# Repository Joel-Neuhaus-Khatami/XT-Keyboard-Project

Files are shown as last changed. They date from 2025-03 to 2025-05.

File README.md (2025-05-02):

XT Keyboard Project:

This repo is for all the files used in designing and manufacturing a mechanical keyboard that I made from scratch
The keyboard itself is a modified XT layout, which was a very popular layout for 1980's keyboards.

The case is inspired by the IBM Model F77, Cherry G80-0418 and the modern NCR80.
Later angularity and side-bezel thickness was inspired by the Pravetz 16 from the Soviet Union and various NCR G80 varieties, for example the NCR G80-0478.

The pcb is designed with Kailh Hotswap Sockets (Although I just soldered my switches directly), all of which are south facing to avoid Cherry profile interference. 
In addition, the pcb supports many different layout varieties, such as stepped caps lock, split left- and right shift, and split backspace compatibility.
These layouts have also been designed to have the correct clearance for the Hotswap footprint.
The PCB was originally designed with using the ATMega32u4, but after a failed iteration, it was replaced with an RP2040 PCB design instead.
Using the RP2040 enabled QMK firmware compatibility + VIA.
Due to the case dimensions, the pcb does not have an onboard USB type C recepticle, rather using a 4-pin Molex Pico EZmate connector and a daughterboard,
in this instance the UDB (Unified Daughterboard) C4.
The new RP2040 based pcb introduces new quality of life features, such as readily available GND, 3V, RESET, SWD and SWC pins for ISP programming, making troubleshooting a lot simpler
should there be need to program the chip's bootloader.

1. Layout

Capture2

The layout is a mix of the standard HHKB for the Alphanumerical section, XT-esque left side F-row and a 3x5 1U grid inspired by the IBM Model F-77

2. Schematics

Early visualization of switch matrix (This layout was changed tremendously due to later solutions for multiple layouts)
switch_matrix

Switch matrix translated to Kicad schematics
pcb_v3

3. Case

Top case w/ plate


Top and Bottom case side profile



Back view including slit for UDB implementation


Inside view of Top case, showing plate top mount + UDB implementation


Inside view of Bottom case


Bottom


To be posted:
Produced aluminium case

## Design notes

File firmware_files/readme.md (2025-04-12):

# jxt

jxt

*A short description of the keyboard/project*

* Keyboard Maintainer: [Joel Ramin Neuhaus-Khatami](https://github.com/Joel Ramin Neuhaus-Khatami)
* Hardware Supported: *The PCBs, controllers supported*
* Hardware Availability: *Links to where you can find this hardware*

Make example for this keyboard (after setting up your build environment):

    make jxt:default

Flashing example for this keyboard:

    make jxt:default:flash

See the [build environment setup](https://docs.qmk.fm/#/getting_started_build_tools) and the [make instructions](https://docs.qmk.fm/#/getting_started_make_guide) for more information. Brand new to QMK? Start with our [Complete Newbs Guide](https://docs.qmk.fm/#/newbs).

## Bootloader

Enter the bootloader in 3 ways:

* **Bootmagic reset**: Hold down the key at (0,0) in the matrix (usually the top left key or Escape) and plug in the keyboard
* **Physical reset button**: Briefly press the button on the back of the PCB - some may have pads you must short instead
* **Keycode in layout**: Press the key mapped to `QK_BOOT` if it is available

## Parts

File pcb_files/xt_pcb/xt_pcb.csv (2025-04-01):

Source: | C:\Users\Gremlosh\Documents\Programming\Other_projects\XT Keyboard\PCB\xt_pcb\xt_pcb.kicad_sch
Date: | 2025-04-01T20:27:29+0200
Tool: | Eeschema 8.0.8
Generator: | C:\Program Files\KiCad\8.0\bin\scripting\plugins/bom_csv_grouped_by_value.py
Component Count: | 201
Collated Components:
Item | Qty | Reference(s) | Value | LibPart | Footprint | Datasheet | DNP | Datasheet | Description | Footprint | Sim.Device | Sim.Pins
1 | 1 | BT1 | SW_Push | Switch:SW_Push | Button_Switch_SMD:SW_SPST_TL3342 | ~ |  | ~ | Push button switch, generic, two pins | Button_Switch_SMD:SW_SPST_TL3342
2 | 3 | C1, C2, C3 | 100n | Device:C | Capacitor_SMD:C_0402_1005Metric | ~ |  | ~ | Unpolarized capacitor | Capacitor_SMD:C_0402_1005Metric
3 | 2 | C4, C5 | 10u | Device:C | Capacitor_SMD:C_0603_1608Metric | ~ |  | ~ | Unpolarized capacitor | Capacitor_SMD:C_0603_1608Metric
4 | 2 | C6, C7 | 12p | Device:C | Capacitor_SMD:C_0402_1005Metric | ~ |  | ~ | Unpolarized capacitor | Capacitor_SMD:C_0402_1005Metric
5 | 1 | C8 | 1u | Device:C | Capacitor_SMD:C_0402_1005Metric | ~ |  | ~ | Unpolarized capacitor | Capacitor_SMD:C_0402_1005Metric
6 | 86 | D1, D2, D3, D4, D5, D6, D7, D8, D9, D10, D11, D12, D13, D14, D15, D16, D18, D19, D20, D21, D22, D23, D24, D25, D26, D27, D28, D29, D30, D31, D32, D33, D34, D35, D36, D37, D38, D39, D40, D41, D42, D43, D44, D45, D46, D47, D48, D49, D50, D51, D52, D53, D54, D55, D56, D57, D58, D59, D60, D61, D62, D63, D64, D65, D66, D67, D68, D69, D70, D71, D72, D73, D74, D75, D76, D77, D78, D79, D80, D81, D82, D83, D84, D85, D86, D87 | D | Device:D | Diode_SMD:D_SOD-123 | ~ |  | ~ | Diode | Diode_SMD:D_SOD-123 | D | 1=K 2=A
7 | 1 | J1 | Conn_01x04_Socket | Connector:Conn_01x04_Socket | Connector_JST:JST_SH_SM04B-SRSS-TB_1x04-1MP_P1.00mm_Horizontal | ~ |  | ~ | Generic connector, single row, 01x04, script generated | Connector_JST:JST_SH_SM04B-SRSS-TB_1x04-1MP_P1.00mm_Horizontal
8 | 1 | J2 | USB_C_Receptacle_USB2.0_16P | Connector:USB_C_Receptacle_USB2.0_16P | Connector_USB:USB_C_Receptacle_HRO_TYPE-C-31-M-12 | https://www.usb.org/sites/default/files/documents/usb_type-c.zip |  | https://www.usb.org/sites/default/files/documents/usb_type-c.zip | USB 2.0-only 16P Type-C Receptacle connector | Connector_USB:USB_C_Receptacle_HRO_TYPE-C-31-M-12
9 | 1 | R1 | 10k | Device:R | Resistor_SMD:R_0402_1005Metric | ~ |  | ~ | Resistor | Resistor_SMD:R_0402_1005Metric
10 | 2 | R2, R3 | 22 | Device:R | Resistor_SMD:R_0402_1005Metric | ~ |  | ~ | Resistor | Resistor_SMD:R_0402_1005Metric
11 | 2 | R4, R5 | 5k1 | Device:R | Resistor_SMD:R_0402_1005Metric | ~ |  | ~ | Resistor | Resistor_SMD:R_0402_1005Metric
12 | 1 | SW1 | SW_Push | Switch:SW_Push | PCM_Switch_Keyboard_Hotswap_Kailh:SW_Hotswap_Kailh_MX_Plated_2.00u | ~ |  | ~ | Push button switch, generic, two pins | PCM_Switch_Keyboard_Hotswap_Kailh:SW_Hotswap_Kailh_MX_Plated_2.00u
13 | 77 | SW2, SW3, SW4, SW5, SW6, SW7, SW8, SW9, SW10, SW11, SW12, SW13, SW14, SW15, SW16, SW17, SW19, SW20, SW21, SW22, SW23, SW25, SW26, SW27, SW28, SW29, SW30, SW31, SW32, SW33, SW34, SW35, SW36, SW38, SW39, SW40, SW42, SW43, SW45, SW46, SW47, SW48, SW49, SW50, SW51, SW52, SW53, SW54, SW55, SW57, SW58, SW59, SW60, SW62, SW64, SW66, SW67, SW68, SW69, SW70, SW71, SW72, SW73, SW74, SW75, SW76, SW77, SW78, SW79, SW80, SW81, SW82, SW83, SW87, SW88, SW89, SW90 | SW_Push | Switch:SW_Push | PCM_Switch_Keyboard_Hotswap_Kailh:SW_Hotswap_Kailh_MX_Plated_1.00u | ~ |  | ~ | Push button switch, generic, two pins | PCM_Switch_Keyboard_Hotswap_Kailh:SW_Hotswap_Kailh_MX_Plated_1.00u
14 | 2 | SW24, SW37 | SW_Push | Switch:SW_Push | PCM_Switch_Keyboard_Hotswap_Kailh:SW_Hotswap_Kailh_MX_Plated_1.50u | ~ |  | ~ | Push button switch, generic, two pins | PCM_Switch_Keyboard_Hotswap_Kailh:SW_Hotswap_Kailh_MX_Plated_1.50u
15 | 2 | SW41, SW97 | SW_Push | Switch:SW_Push | PCM_Switch_Keyboard_Hotswap_Kailh:SW_Hotswap_Kailh_MX_Plated_1.75u | ~ |  | ~ | Push button switch, generic, two pins | PCM_Switch_Keyboard_Hotswap_Kailh:SW_Hotswap_Kailh_MX_Plated_1.75u
16 | 4 | SW44, SW63, SW84, SW86 | SW_Push | Switch:SW_Push | PCM_Switch_Keyboard_Hotswap_Kailh:SW_Hotswap_Kailh_MX_Plated_1.25u | ~ |  | ~ | Push button switch, generic, two pins | PCM_Switch_Keyboard_Hotswap_Kailh:SW_Hotswap_Kailh_MX_Plated_1.25u
17 | 2 | SW56, SW61 | SW_Push | Switch:SW_Push | PCM_Switch_Keyboard_Hotswap_Kailh:SW_Hotswap_Kailh_MX_Plated_2.25u | ~ |  | ~ | Push button switch, generic, two pins | PCM_Switch_Keyboard_Hotswap_Kailh:SW_Hotswap_Kailh_MX_Plated_2.25u
18 | 1 | SW85 | SW_Push | Switch:SW_Push | PCM_Switch_Keyboard_Hotswap_Kailh:SW_Hotswap_Kailh_MX_Plated_6.25u | ~ |  | ~ | Push button switch, generic, two pins | PCM_Switch_Keyboard_Hotswap_Kailh:SW_Hotswap_Kailh_MX_Plated_6.25u
19 | 1 | SW91 | SW_Push | Switch:SW_Push | PCM_Mounting_Keyboard_Stabilizer:Stabilizer_Cherry_MX_6.25u | ~ |  | ~ | Push button switch, generic, two pins | PCM_Mounting_Keyboard_Stabilizer:Stabilizer_Cherry_MX_6.25u
20 | 4 | SW92, SW93, SW94, SW95 | SW_Push | Switch:SW_Push | PCM_Mounting_Keyboard_Stabilizer:Stabilizer_Cherry_MX_2.00u | ~ |  | ~ | Push button switch, generic, two pins | PCM_Mounting_Keyboard_Stabilizer:Stabilizer_Cherry_MX_2.00u
21 | 1 | SW96 | SW_Push | Switch:SW_Push | PCM_Switch_Keyboard_Hotswap_Kailh:SW_Hotswap_Kailh_MX_Plated_2.75u | ~ |  | ~ | Push button switch, generic, two pins | PCM_Switch_Keyboard_Hotswap_Kailh:SW_Hotswap_Kailh_MX_Plated_2.75u
22 | 1 | U1 | AMS1117-3.3 | Regulator_Linear:AMS1117-3.3 | Package_TO_SOT_SMD:SOT-223-3_TabPin2 | http://www.advanced-monolithic.com/pdf/ds1117.pdf |  | http://www.advanced-monolithic.com/pdf/ds1117.pdf | 1A Low Dropout regulator, positive, 3.3V fixed output, SOT-223 | Package_TO_SOT_SMD:SOT-223-3_TabPin2
23 | 1 | U2 | ATmega32U4-A | MCU_Microchip_ATmega:ATmega32U4-A | Package_QFP:TQFP-44_10x10mm_P0.8mm | http://ww1.microchip.com/downloads/en/DeviceDoc/Atmel-7766-8-bit-AVR-ATmega16U4-32U4_Datasheet.pdf |  | http://ww1.microchip.com/downloads/en/DeviceDoc/Atmel-7766-8-bit-AVR-ATmega16U4-32U4_Datasheet.pdf | 16MHz, 32kB Flash, 2.5kB SRAM, 1kB EEPROM, USB 2.0, TQFP-44 | Package_QFP:TQFP-44_10x10mm_P0.8mm
24 | 1 | U3 | USB6B1 | Power_Protection:USB6B1 | Package_SO:SOIC-8_3.9x4.9mm_P1.27mm | http://www.st.com/content/ccc/resource/technical/document/datasheet/3e/ec/b2/54/b2/76/47/90/CD00001361.pdf/files/CD00001361.pdf/jcr:content/translations/en.CD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 |  | http://www.st.com/content/ccc/resource/technical/document/datasheet/3e/ec/b2/54/b2/76/47/90/CD00001361.pdf/files/CD00001361.pdf/jcr:content/translations/en.CD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 | 5V Data line protection | Package_SO:SOIC-8_3.9x4.9mm_P1.27mm
25 | 1 | Y1 | Crystal_GND24_Small | Device:Crystal_GND24_Small | Crystal:Crystal_SMD_3225-4Pin_3.2x2.5mm | ~ |  | ~ | Four pin crystal, GND on pins 2 and 4, small symbol | Crystal:Crystal_SMD_3225-4Pin_3.2x2.5mm

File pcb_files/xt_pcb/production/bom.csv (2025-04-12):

Designator | Footprint | Quantity | Value | LCSC Part #
BT1 | SW_SPST_TL3342 | 1 | SW_Push
C1, C2, C3 | 0402 | 3 | 100n
C4, C5 | 0603 | 2 | 10u
C6, C7 | 0402 | 2 | 12p
C8 | 0402 | 1 | 1u
D1, D10, D11, D12, D13, D14, D15, D16, D18, D19, D2, D20, D21, D22, D23, D24, D25, D26, D27, D28, D29, D3, D30, D31, D32, D33, D34, D35, D36, D37, D38, D39, D4, D40, D41, D42, D43, D44, D45, D46, D47, D48, D49, D5, D50, D51, D52, D53, D54, D55, D56, D57, D58, D59, D6, D60, D61, D62, D63, D64, D65, D66, D67, D68, D69, D7, D70, D71, D72, D73, D74, D75, D76, D77, D78, D79, D8, D80, D81, D82, D83, D84, D85, D86, D87, D9 | D_SOD-123 | 86 | D
J1 | MOLEX_781710004 | 1 | Conn_01x04_Socket
R1 | 0402 | 1 | 10k
R2, R3 | 0402 | 2 | 22
SW1 | SW_Hotswap_Kailh_MX_Plated_2.00u | 1 | SW_Push
SW10, SW11, SW12, SW13, SW14, SW15, SW16, SW17, SW19, SW2, SW20, SW21, SW22, SW23, SW25, SW26, SW27, SW28, SW29, SW3, SW30, SW31, SW32, SW33, SW34, SW35, SW36, SW38, SW39, SW4, SW40, SW42, SW43, SW45, SW46, SW47, SW48, SW49, SW5, SW50, SW51, SW52, SW53, SW54, SW55, SW57, SW58, SW59, SW6, SW60, SW62, SW64, SW66, SW67, SW68, SW69, SW7, SW70, SW71, SW72, SW73, SW74, SW75, SW76, SW77, SW78, SW79, SW8, SW80, SW81, SW82, SW83, SW87, SW88, SW89, SW9, SW90 | SW_Hotswap_Kailh_MX_Plated_1.00u | 77 | SW_Push
SW24, SW37 | SW_Hotswap_Kailh_MX_Plated_1.50u | 2 | SW_Push
SW41, SW97 | SW_Hotswap_Kailh_MX_Plated_1.75u | 2 | SW_Push
SW44, SW63, SW84, SW86 | SW_Hotswap_Kailh_MX_Plated_1.25u | 4 | SW_Push
SW56, SW61 | SW_Hotswap_Kailh_MX_Plated_2.25u | 2 | SW_Push
SW85 | SW_Hotswap_Kailh_MX_Plated_6.25u | 1 | SW_Push
SW91 | Stabilizer_Cherry_MX_6.25u | 1 | SW_Push
SW92, SW93, SW94, SW95 | Stabilizer_Cherry_MX_2.00u | 4 | SW_Push
SW96 | SW_Hotswap_Kailh_MX_Plated_2.75u | 1 | SW_Push
U1 | SOT-223-3_TabPin2 | 1 | AMS1117-3.3
U2 | TQFP-44_10x10mm_P0.8mm | 1 | ATmega32U4-A
Y1 | Crystal_SMD_3225-4Pin_3.2x2.5mm | 1 | Crystal_GND24_Small

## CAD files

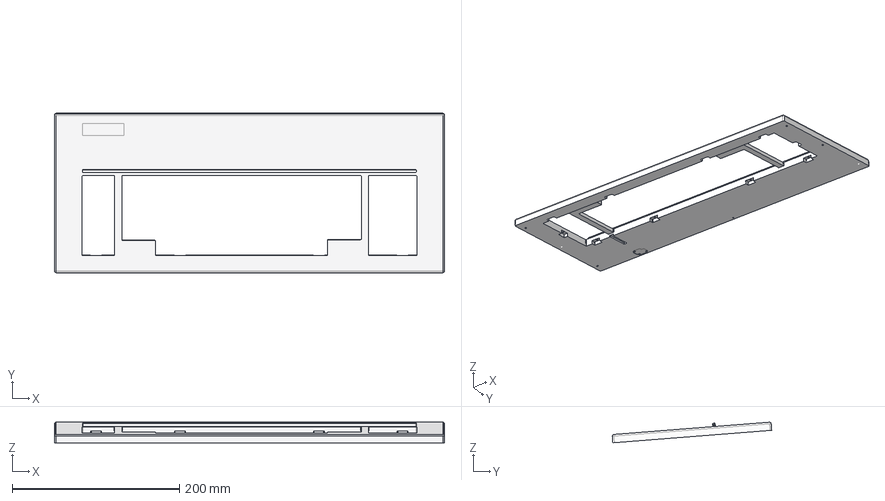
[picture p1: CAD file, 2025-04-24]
case_files/top_case.step
467.1 x 191.0 x 24.7 mm

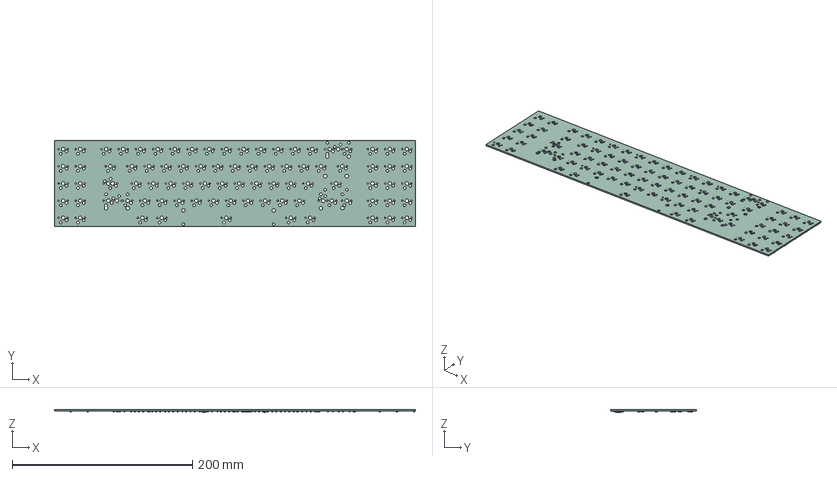
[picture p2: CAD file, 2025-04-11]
pcb_files/xt_pcb/xt_pcb.step
400.1 x 95.2 x 3.35 mm
D_SOD_123 x 86
R_0402_1005Metric x 3
SOT_223
C_0402_1005Metric x 6
TQFP_44_10x10mm_P08mm
Crystal_SMD_3225-4Pin_3.2x2.5mm
C_0603_1608Metric x 2
SW_SPST_TL3342
xt_pcb_PCB

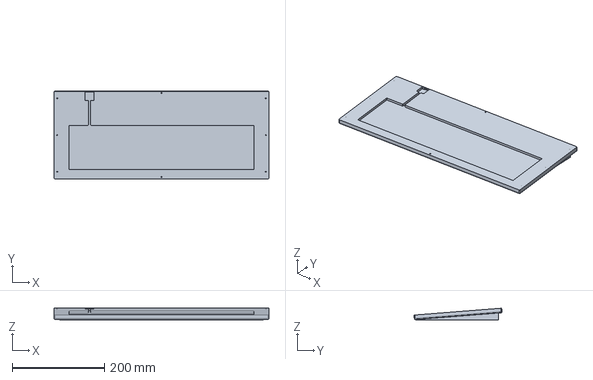
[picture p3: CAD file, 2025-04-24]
case_files/bottom_case.step
467.0 x 191.0 x 25.3 mm

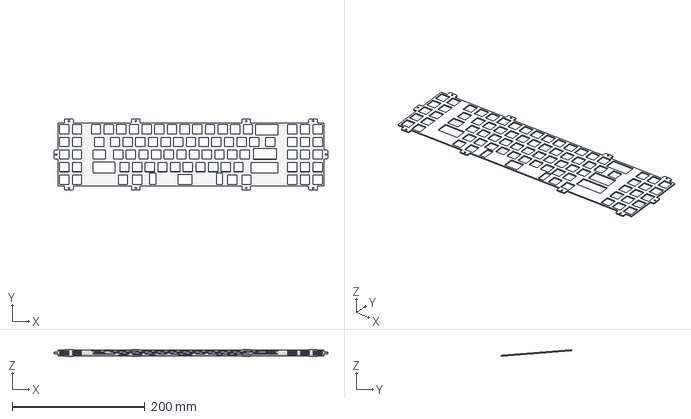
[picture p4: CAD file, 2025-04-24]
case_files/plate.step
412.0 x 107.1 x 9.91 mm

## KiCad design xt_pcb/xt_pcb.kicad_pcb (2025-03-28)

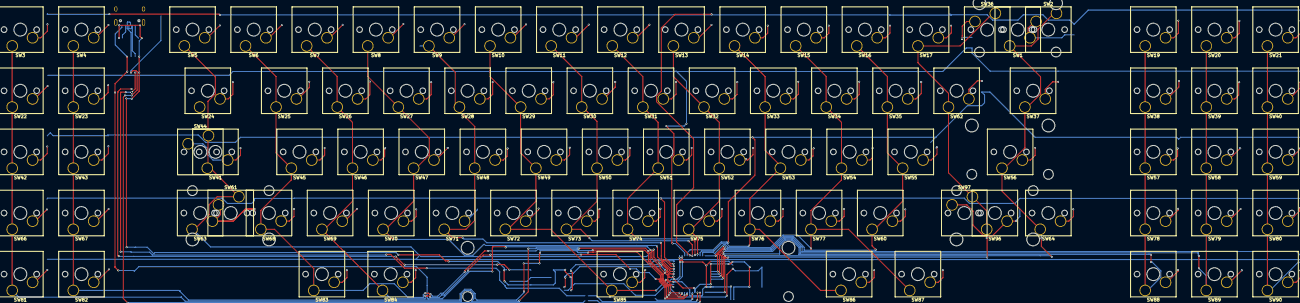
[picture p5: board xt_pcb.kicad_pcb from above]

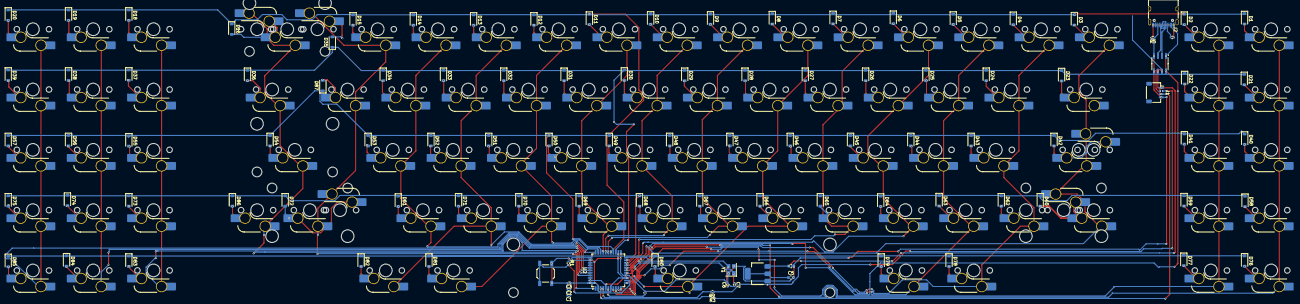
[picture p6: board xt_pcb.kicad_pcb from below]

Board: 2 copper layers, 201 parts (106 on the bottom side), 126 nets.

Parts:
BT1: SW_Push; SW_SPST_TL3342
C1, C2, C3: 100n; C_0402_1005Metric
C4, C5: 10u; C_0603_1608Metric
C6, C7: 12p; C_0402_1005Metric
C8: 1u; C_0402_1005Metric
D1, D2, D3, D4, D5, D6, D7, D8, D9, D10, D11, D12, D13, D14, D15, D16, D18, D19, D20, D21, D22, D23, D24, D25, D26, D27, D28, D29, D30, D31, D32, D33, D34, D35, D36, D37, D38, D39, D40, D41, D42, D43, D44, D45, D46, D47, D48, D49, D50, D51, D52, D53, D54, D55, D56, D57, D58, D59, D60, D61, D62, D63, D64, D65, D66, D67, D68, D69, D70, D71, D72, D73, D74, D75, D76, D77, D78, D79, D80, D81, D82, D83, D84, D85, D86, D87: D; D_SOD-123
J1: Conn_01x04_Socket; JST_SH_SM04B-SRSS-TB_1x04-1MP_P1.00mm_Horizontal
J2: USB_C_Receptacle_USB2.0_16P; USB_C_Receptacle_HRO_TYPE-C-31-M-12
R1: 10k; R_0402_1005Metric
R2, R3: 22; R_0402_1005Metric
R4, R5: 5k1; R_0402_1005Metric
SW1: SW_Push; SW_Hotswap_Kailh_MX_Plated_2.00u
SW2, SW3, SW4, SW5, SW6, SW7, SW8, SW9, SW10, SW11, SW12, SW13, SW14, SW15, SW16, SW17, SW19, SW20, SW21, SW22, SW23, SW25, SW26, SW27, SW28, SW29, SW30, SW31, SW32, SW33, SW34, SW35, SW36, SW38, SW39, SW40, SW42, SW43, SW45, SW46, SW47, SW48, SW49, SW50, SW51, SW52, SW53, SW54, SW55, SW57, SW58, SW59, SW60, SW62, SW64, SW66, SW67, SW68, SW69, SW70, SW71, SW72, SW73, SW74, SW75, SW76, SW77, SW78, SW79, SW80, SW81, SW82, SW83, SW87, SW88, SW89, SW90: SW_Push; SW_Hotswap_Kailh_MX_Plated_1.00u
SW24, SW37: SW_Push; SW_Hotswap_Kailh_MX_Plated_1.50u
SW41, SW97: SW_Push; SW_Hotswap_Kailh_MX_Plated_1.75u
SW44, SW63, SW84, SW86: SW_Push; SW_Hotswap_Kailh_MX_Plated_1.25u
SW56, SW61: SW_Push; SW_Hotswap_Kailh_MX_Plated_2.25u
SW85: SW_Push; SW_Hotswap_Kailh_MX_Plated_6.25u
SW91: SW_Push; Stabilizer_Cherry_MX_6.25u
SW92, SW93, SW94, SW95: SW_Push; Stabilizer_Cherry_MX_2.00u
SW96: SW_Push; SW_Hotswap_Kailh_MX_Plated_2.75u
U1: AMS1117-3.3; SOT-223-3_TabPin2
U2: ATmega32U4-A; TQFP-44_10x10mm_P0.8mm
U3: USB6B1; SOIC-8_3.9x4.9mm_P1.27mm
Y1: Crystal_GND24_Small; Crystal_SMD_3225-4Pin_3.2x2.5mm

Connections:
+3.3V: C5.1, U1.2 (VO)
+5V: C4.1, J1.1, U1.3 (VI)
C1: SW3.2, SW22.2, SW42.2, SW66.2, SW81.2, U2.11 (PB3)
C2: SW4.2, SW23.2, SW43.2, SW67.2, SW82.2, U2.9 (PB1)
C3: SW5.2, SW24.2, SW41.2, SW44.2, SW61.2, SW63.2, U2.18 (PD0)
C4: SW6.2, SW25.2, SW45.2, SW68.2, SW83.2, U2.10 (PB2)
C5: SW7.2, SW26.2, SW46.2, SW69.2, SW84.2, U2.8 (PB0)
C6: SW8.2, SW27.2, SW47.2, SW70.2, U2.19 (PD1)
C7: SW9.2, SW28.2, SW48.2, SW71.2, U2.20 (PD2)
C8: SW10.2, SW29.2, SW49.2, SW72.2, SW85.2, U2.12 (PB7)
C9: SW11.2, SW30.2, SW50.2, SW73.2, U2.28 (PB4)
C10: SW12.2, SW31.2, SW51.2, SW74.2, U2.29 (PB5)
C11: SW13.2, SW32.2, SW52.2, SW75.2, U2.30 (PB6)
C12: SW14.2, SW33.2, SW53.2, SW76.2, SW86.2, U2.31 (PC6)
C13: SW15.2, SW34.2, SW54.2, SW77.2, SW87.2, U2.32 (PC7)
C14: SW16.2, SW35.2, SW55.2, SW60.2, U2.33 (~HWB/PE2)
C15: SW17.2, SW36.2, SW62.2, SW96.2, SW97.2, U2.1 (PE6)
C16: SW1.2, SW2.2, SW37.2, SW56.2, SW64.2, U2.41 (PF0)
C17: SW19.2, SW38.2, SW57.2, SW78.2, SW88.2, U2.40 (PF1)
C18: SW20.2, SW39.2, SW58.2, SW79.2, SW89.2, U2.39 (PF4)
C19: SW21.2, SW40.2, SW59.2, SW80.2, SW90.2, U2.38 (PF5)
D+: J1.2, R2.1, U3.6 (I/O2)
D-: J1.3, R3.1, U3.7 (I/O1)
GND: BT1.1, C1.2, C2.2, C3.2, C4.2, C5.2, C6.2, C7.2, C8.2, J1.4, J2.A1 (GND), J2.A12 (GND), J2.B1 (GND), J2.B12 (GND), R4.2, R5.2, U1.1 (GND), U2.5 (UGND), U2.15 (GND), U2.23 (GND), U2.35 (GND), U2.43 (GND), U3.4 (GND), U3.5 (GND), Y1.2, Y1.4
unnamed: D1.2 (A), SW3.1
unnamed: D2.2 (A), SW4.1
unnamed: D3.2 (A), SW5.1
unnamed: D4.2 (A), SW6.1
unnamed: D5.2 (A), SW7.1
unnamed: D6.2 (A), SW8.1
unnamed: D7.2 (A), SW9.1
unnamed: D8.2 (A), SW10.1
unnamed: D9.2 (A), SW11.1
unnamed: D10.2 (A), SW12.1
unnamed: D11.2 (A), SW13.1
unnamed: D12.2 (A), SW14.1
unnamed: D13.2 (A), SW15.1
unnamed: D14.2 (A), SW16.1
unnamed: D15.2 (A), SW17.1
unnamed: D16.2 (A), SW1.1, SW2.1
unnamed: D18.2 (A), SW19.1
unnamed: D19.2 (A), SW20.1
unnamed: D20.2 (A), SW21.1
unnamed: D21.2 (A), SW22.1
unnamed: D22.2 (A), SW23.1
unnamed: D23.2 (A), SW24.1
unnamed: D24.2 (A), SW25.1
unnamed: D25.2 (A), SW26.1
unnamed: D26.2 (A), SW27.1
unnamed: D27.2 (A), SW28.1
unnamed: D28.2 (A), SW29.1
unnamed: D29.2 (A), SW30.1
unnamed: D30.2 (A), SW31.1
unnamed: D31.2 (A), SW32.1
unnamed: D32.2 (A), SW33.1
unnamed: D33.2 (A), SW34.1
unnamed: D34.2 (A), SW35.1
unnamed: D35.2 (A), SW36.1
unnamed: D36.2 (A), SW37.1
unnamed: D37.2 (A), SW38.1
unnamed: D38.2 (A), SW39.1
unnamed: D39.2 (A), SW40.1
unnamed: D40.2 (A), SW42.1
unnamed: D41.2 (A), SW43.1
unnamed: D42.2 (A), SW41.1, SW44.1
unnamed: D43.2 (A), SW45.1
unnamed: D44.2 (A), SW46.1
unnamed: D45.2 (A), SW47.1
unnamed: D46.2 (A), SW48.1
unnamed: D47.2 (A), SW49.1
unnamed: D48.2 (A), SW50.1
unnamed: D49.2 (A), SW51.1
unnamed: D50.2 (A), SW52.1
unnamed: D51.2 (A), SW53.1
unnamed: D52.2 (A), SW54.1
unnamed: D53.2 (A), SW55.1
unnamed: D54.2 (A), SW56.1
unnamed: D55.2 (A), SW57.1
unnamed: D56.2 (A), SW58.1
unnamed: D57.2 (A), SW59.1
unnamed: D58.2 (A), SW66.1
unnamed: D59.2 (A), SW67.1
unnamed: D60.2 (A), SW61.1, SW63.1
unnamed: D61.2 (A), SW60.1
unnamed: D62.2 (A), SW68.1
unnamed: D63.2 (A), SW69.1
unnamed: D64.2 (A), SW70.1
unnamed: D65.2 (A), SW71.1
unnamed: D66.2 (A), SW72.1
unnamed: D67.2 (A), SW73.1
unnamed: D68.2 (A), SW74.1
unnamed: D69.2 (A), SW75.1
unnamed: D70.2 (A), SW76.1
unnamed: D71.2 (A), SW77.1
unnamed: D72.2 (A), SW96.1, SW97.1
unnamed: D73.2 (A), SW78.1
unnamed: D74.2 (A), SW79.1
unnamed: D75.2 (A), SW80.1
unnamed: D76.2 (A), SW81.1
unnamed: D77.2 (A), SW82.1
unnamed: D78.2 (A), SW83.1
unnamed: D79.2 (A), SW84.1
unnamed: D80.2 (A), SW85.1
unnamed: D81.2 (A), SW86.1
unnamed: D82.2 (A), SW87.1
unnamed: D83.2 (A), SW88.1
unnamed: D84.2 (A), SW89.1
unnamed: D85.2 (A), SW90.1
unnamed: D86.2 (A), SW64.1
unnamed: D87.2 (A), SW62.1
unnamed: J2.A5 (CC1), R4.1
unnamed: J2.B5 (CC2), R5.1
unnamed: J2.A6 (D+), J2.B6 (D+), U3.3 (I/O2)
unnamed: J2.A7 (D-), J2.B7 (D-), U3.2 (I/O1)
unnamed: R2.2, U2.4 (D+)
unnamed: R3.2, U2.3 (D-)
unnamed: C8.1, U2.6 (UCAP)
unnamed: C6.1, U2.17 (XTAL1), Y1.3
unnamed: C7.1, U2.16 (XTAL2), Y1.1
unnamed: BT1.2, R1.2, U2.13 (~RESET)
R1: D1.1 (K), D2.1 (K), D3.1 (K), D4.1 (K), D5.1 (K), D6.1 (K), D7.1 (K), D8.1 (K), D9.1 (K), D10.1 (K), D11.1 (K), D12.1 (K), D13.1 (K), D14.1 (K), D15.1 (K), D16.1 (K), D18.1 (K), D19.1 (K), D20.1 (K), U2.27 (PD7)
R2: D21.1 (K), D22.1 (K), D23.1 (K), D24.1 (K), D25.1 (K), D26.1 (K), D27.1 (K), D28.1 (K), D29.1 (K), D30.1 (K), D31.1 (K), D32.1 (K), D33.1 (K), D34.1 (K), D35.1 (K), D36.1 (K), D37.1 (K), D38.1 (K), D39.1 (K), U2.25 (PD4)
R3: D40.1 (K), D41.1 (K), D42.1 (K), D43.1 (K), D44.1 (K), D45.1 (K), D46.1 (K), D47.1 (K), D48.1 (K), D49.1 (K), D50.1 (K), D51.1 (K), D52.1 (K), D53.1 (K), D54.1 (K), D55.1 (K), D56.1 (K), D57.1 (K), D87.1 (K), U2.26 (PD6)
R4: D58.1 (K), D59.1 (K), D60.1 (K), D61.1 (K), D62.1 (K), D63.1 (K), D64.1 (K), D65.1 (K), D66.1 (K), D67.1 (K), D68.1 (K), D69.1 (K), D70.1 (K), D71.1 (K), D72.1 (K), D73.1 (K), D74.1 (K), D75.1 (K), D86.1 (K), U2.21 (PD3)
R5: D76.1 (K), D77.1 (K), D78.1 (K), D79.1 (K), D80.1 (K), D81.1 (K), D82.1 (K), D83.1 (K), D84.1 (K), D85.1 (K), U2.22 (PD5)
VBUS: C1.1, C2.1, C3.1, J2.A4 (VBUS), J2.A9 (VBUS), J2.B4 (VBUS), J2.B9 (VBUS), R1.1, U2.2 (UVCC), U2.7 (VBUS), U2.14 (VCC), U2.24 (AVCC), U2.34 (VCC), U2.44 (AVCC), U3.1 (VBUS), U3.8 (VBUS)

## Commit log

2025-03-17 Version 15 of keyboard case+plate added
2025-03-27 Plate mounting solution + slimmer EDB slot
2025-03-27 Type C Receptible + EDB added
    [xt_pcb.kicad_pcb, xt_pcb.kicad_sch]
2025-03-27 Adjusted top mount
2025-03-27 basic tracing added to pcb
    [xt_pcb.kicad_pcb, xt_pcb.kicad_sch]
2025-03-27 Switch matrix labels
    [xt_pcb.kicad_pcb, xt_pcb.kicad_sch]
2025-03-28 tracing finished
    [xt_pcb.kicad_pcb, xt_pcb.kicad_sch]
2025-03-28 Edge cut + stabilizer clearance added
2025-03-30 DRC + Silkscreen cleanup
2025-03-31 adjusted nav cluster spacing + generated step file for fusion
    [xt_pcb.step]
2025-03-31 gerbers + drill
    [xt_pcb-B_Cu.gbr, xt_pcb-B_Mask.gbr, xt_pcb-B_Paste.gbr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]
2025-04-01 updated gerbers
    [xt_pcb-B_Cu.gbr, xt_pcb-B_Mask.gbr, xt_pcb-B_Paste.gbr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]
2025-04-01 production files added
    [bom.csv, designators.csv, positions.csv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]
2025-04-04 More robust top mount solution + threading
    [positions.csv]
2025-04-08 new file structure + UDB type S implementation
    [bom.csv, bottom_case.step, designators.csv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]
2025-04-10 adjusted case files
    [bottom_case.step, plate.step]
2025-04-11 finalized files + UDB C4 implementation
    [bom.csv, bottom_case.step, designators.csv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]
2025-04-12 basic firmware added
    [bom.csv, positions.csv, xt_pcb.kicad_sch]
2025-04-14 further CNC oriented adjustments
    [bottom_case.step, plate.step, top_case.step]
2025-04-16 Thicker bottom case
    [bottom_case.step, plate.step, top_case.step]
2025-04-18 tolerance adjustments
    [bottom_case.step, top_case.step]
2025-04-19 removed UDB 3d Model
    [top_case.step]
2025-04-21 USB C opening improved
    [top_case.step]
2025-04-23 increased case density + bottom case udb
    [bottom_case.step, plate.step, top_case.step]
2025-04-24 tweaked case files
    [bottom_case.step, plate.step, top_case.step]
2025-04-24 symmetry tweaks
    [bottom_case.step, top_case.step]
2025-05-02 new RP2040 pcb
    [untitled.kicad_sch, xt_pcb.kicad_sch]
